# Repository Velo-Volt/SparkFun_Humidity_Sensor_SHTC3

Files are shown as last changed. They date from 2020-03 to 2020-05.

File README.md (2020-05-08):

SparkFun Humidity Sensor - SHTC3 (Qwiic)
========================================

SparkFun Humidity Sensor - SHTC3 (Qwiic) (https://www.sparkfun.com/products/16467)

[*SparkFun Humidity Sensor - SHTC3 (Qwiic)*](https://www.sparkfun.com/products/16467)

The SparkFun Humidity Sensor - SHTC3 (Qwiic) is an I<sup>2</sup>C enabled humidity and temperature sensor.

Repository Contents
-------------------

* **/Documentation** - Data sheets, additional product information
* **/Hardware** - Eagle design files (.brd, .sch)
* **/Production** - Production panel files (.brd)

Documentation
--------------
* **[SHTC3 Arduino Library](https://github.com/sparkfun/SparkFun_SHTC3_Arduino_Library)** - Arduino library for the SHTC3.
* **[Hookup Guide](https://learn.sparkfun.com/tutorials/sparkfun-humidity-sensor-breakout---shtc3-qwiic-hookup-guide)** - Basic hookup guide for the Humidity Sensor - SHTC3 (Qwiic).
* **[SparkFun Fritzing repo](https://github.com/sparkfun/Fritzing_Parts)** - Fritzing diagrams for SparkFun products.
* **[SparkFun 3D Model repo](https://github.com/sparkfun/3D_Models)** - 3D models of SparkFun products. 

Product Versions
----------------
* [SEN-16467](https://www.sparkfun.com/products/16467) - SparkFun Red Version
* [SPX-15074](https://www.sparkfun.com/products/15074) - Original SparkX version of the Humidity Sensor - SHTC3 (Qwiic).

License Information
-------------------

This product is _**open source**_! 

Please review the LICENSE.md file for license information. 

If you have any questions or concerns on licensing, please contact techsupport@sparkfun.com.

Distributed as-is; no warranty is given.

- Your friends at SparkFun.

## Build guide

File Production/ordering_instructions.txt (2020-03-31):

panel size, 143x188mm
PCB thickness, 1.6mm
number of layers, 2
soldermask color, Red
silkscreen color, White
oz copper, 1oz
finish, HASL lead free
stencils, top
pcs per panel, 35
min trace width, 0.1778mm / 0.0070in
min drill size, 0.3810mm / 0.0150in

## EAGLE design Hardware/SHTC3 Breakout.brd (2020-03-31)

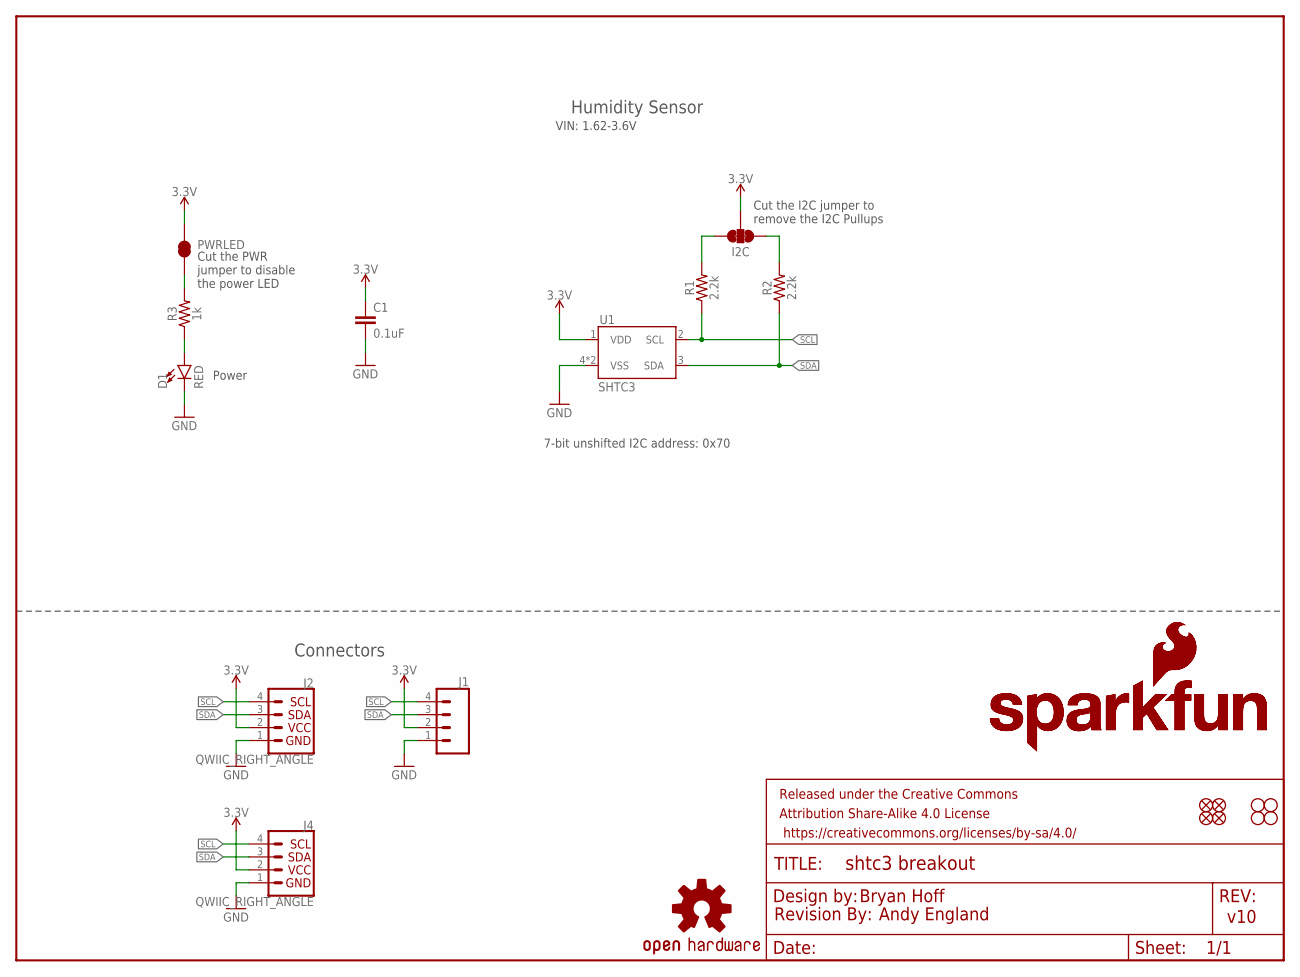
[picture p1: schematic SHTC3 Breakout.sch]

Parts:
C1: 0.1uF; 0603
D1: RED; LED-0603
FRAME1: FRAME-LETTER; CREATIVE_COMMONS
I2C: JUMPER-SMT_3_2-NC_TRACE_SILK; SMT-JUMPER_3_2-NC_TRACE_SILK
J1: CONN_041X04_NO_SILK; 1X04_NO_SILK
J2, J4: QWIIC_RIGHT_ANGLE; JST04_1MM_RA
JP1, JP2, JP5, JP6: FIDUCIALUFIDUCIAL; MICRO-FIDUCIAL
JP3, JP4, JP7, JP8: STAND-OFF
LOGO1: OSHW-LOGOMINI; OSHW-LOGO-MINI
LOGO2, LOGO3: SFE_LOGO_NAME_FLAME.1_INCH; SFE_LOGO_NAME_FLAME_.1
LOGO4: REVISION
PWRLED: JUMPER-SMT_2_NC_TRACE_SILK; SMT-JUMPER_2_NC_TRACE_SILK
R1, R2: 2.2k; 0603
R3: 1k; 0603
U1: SHTC3

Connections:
3.3V: C1.1, I2C.2, J1.2, J2.2, J4.2, PWRLED.2, U1.1 (VDD)
GND: C1.2, D1.C, J1.1, J2.1, J4.1, U1.4 (VSS), U1.5 (VSS)
unnamed: I2C.3, R1.2
unnamed: I2C.1, R2.2
unnamed: D1.A, R3.1
unnamed: PWRLED.1, R3.2
SCL: J1.4, J2.4, J4.4, R1.1, U1.2 (SCL)
SDA: J1.3, J2.3, J4.3, R2.1, U1.3 (SDA)

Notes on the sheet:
Bryan Hoff
v10
7-bit unshifted I2C address: 0x70
Power
Connectors
Cut the I2C jumper to remove the I2C Pullups
Humidity Sensor
Cut the PWR jumper to disable the power LED
Andy England
VIN: 1.62-3.6V

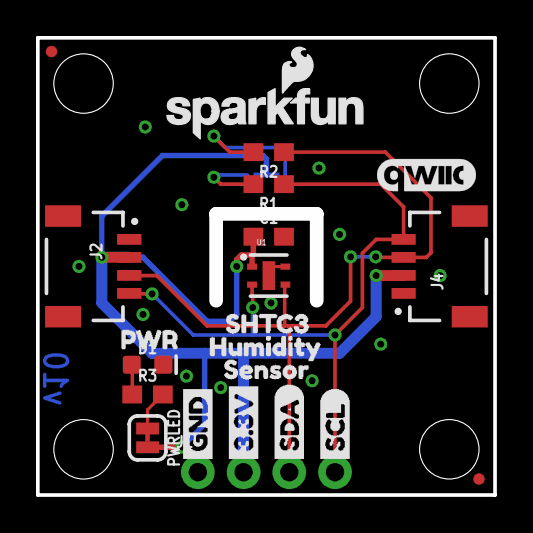
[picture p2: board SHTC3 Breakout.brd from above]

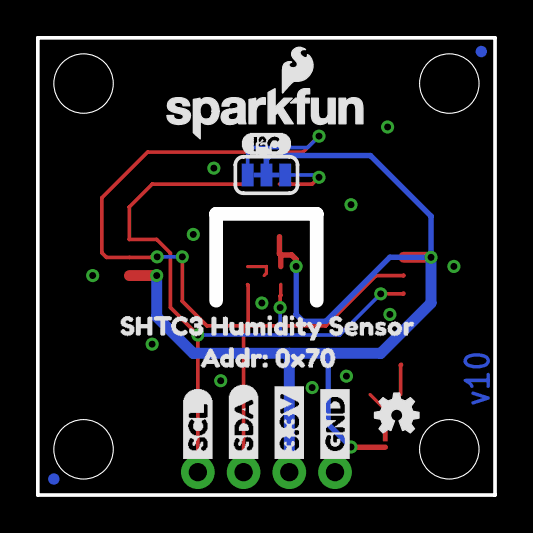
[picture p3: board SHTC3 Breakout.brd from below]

Board: 2 copper layers, 25.4 x 25.4 mm, 40 parts (12 on the bottom side), 8 nets.

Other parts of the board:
U$1: ADDR#_0X700
U$2: PWR_TO
U$3, U$22: GND1
U$4, U$21: 3#3V2
U$5, U$27: SDA8
U$6, U$26: SCL9
U$7: SHTC3_HUMIDITY_SENSOR2
U$8: _SHTC31
U$9: I_SUPER2_C-()-03
U$10: HUMIDITY2
U$11: QWIIC_5.5MM
U$12: SENSOR0

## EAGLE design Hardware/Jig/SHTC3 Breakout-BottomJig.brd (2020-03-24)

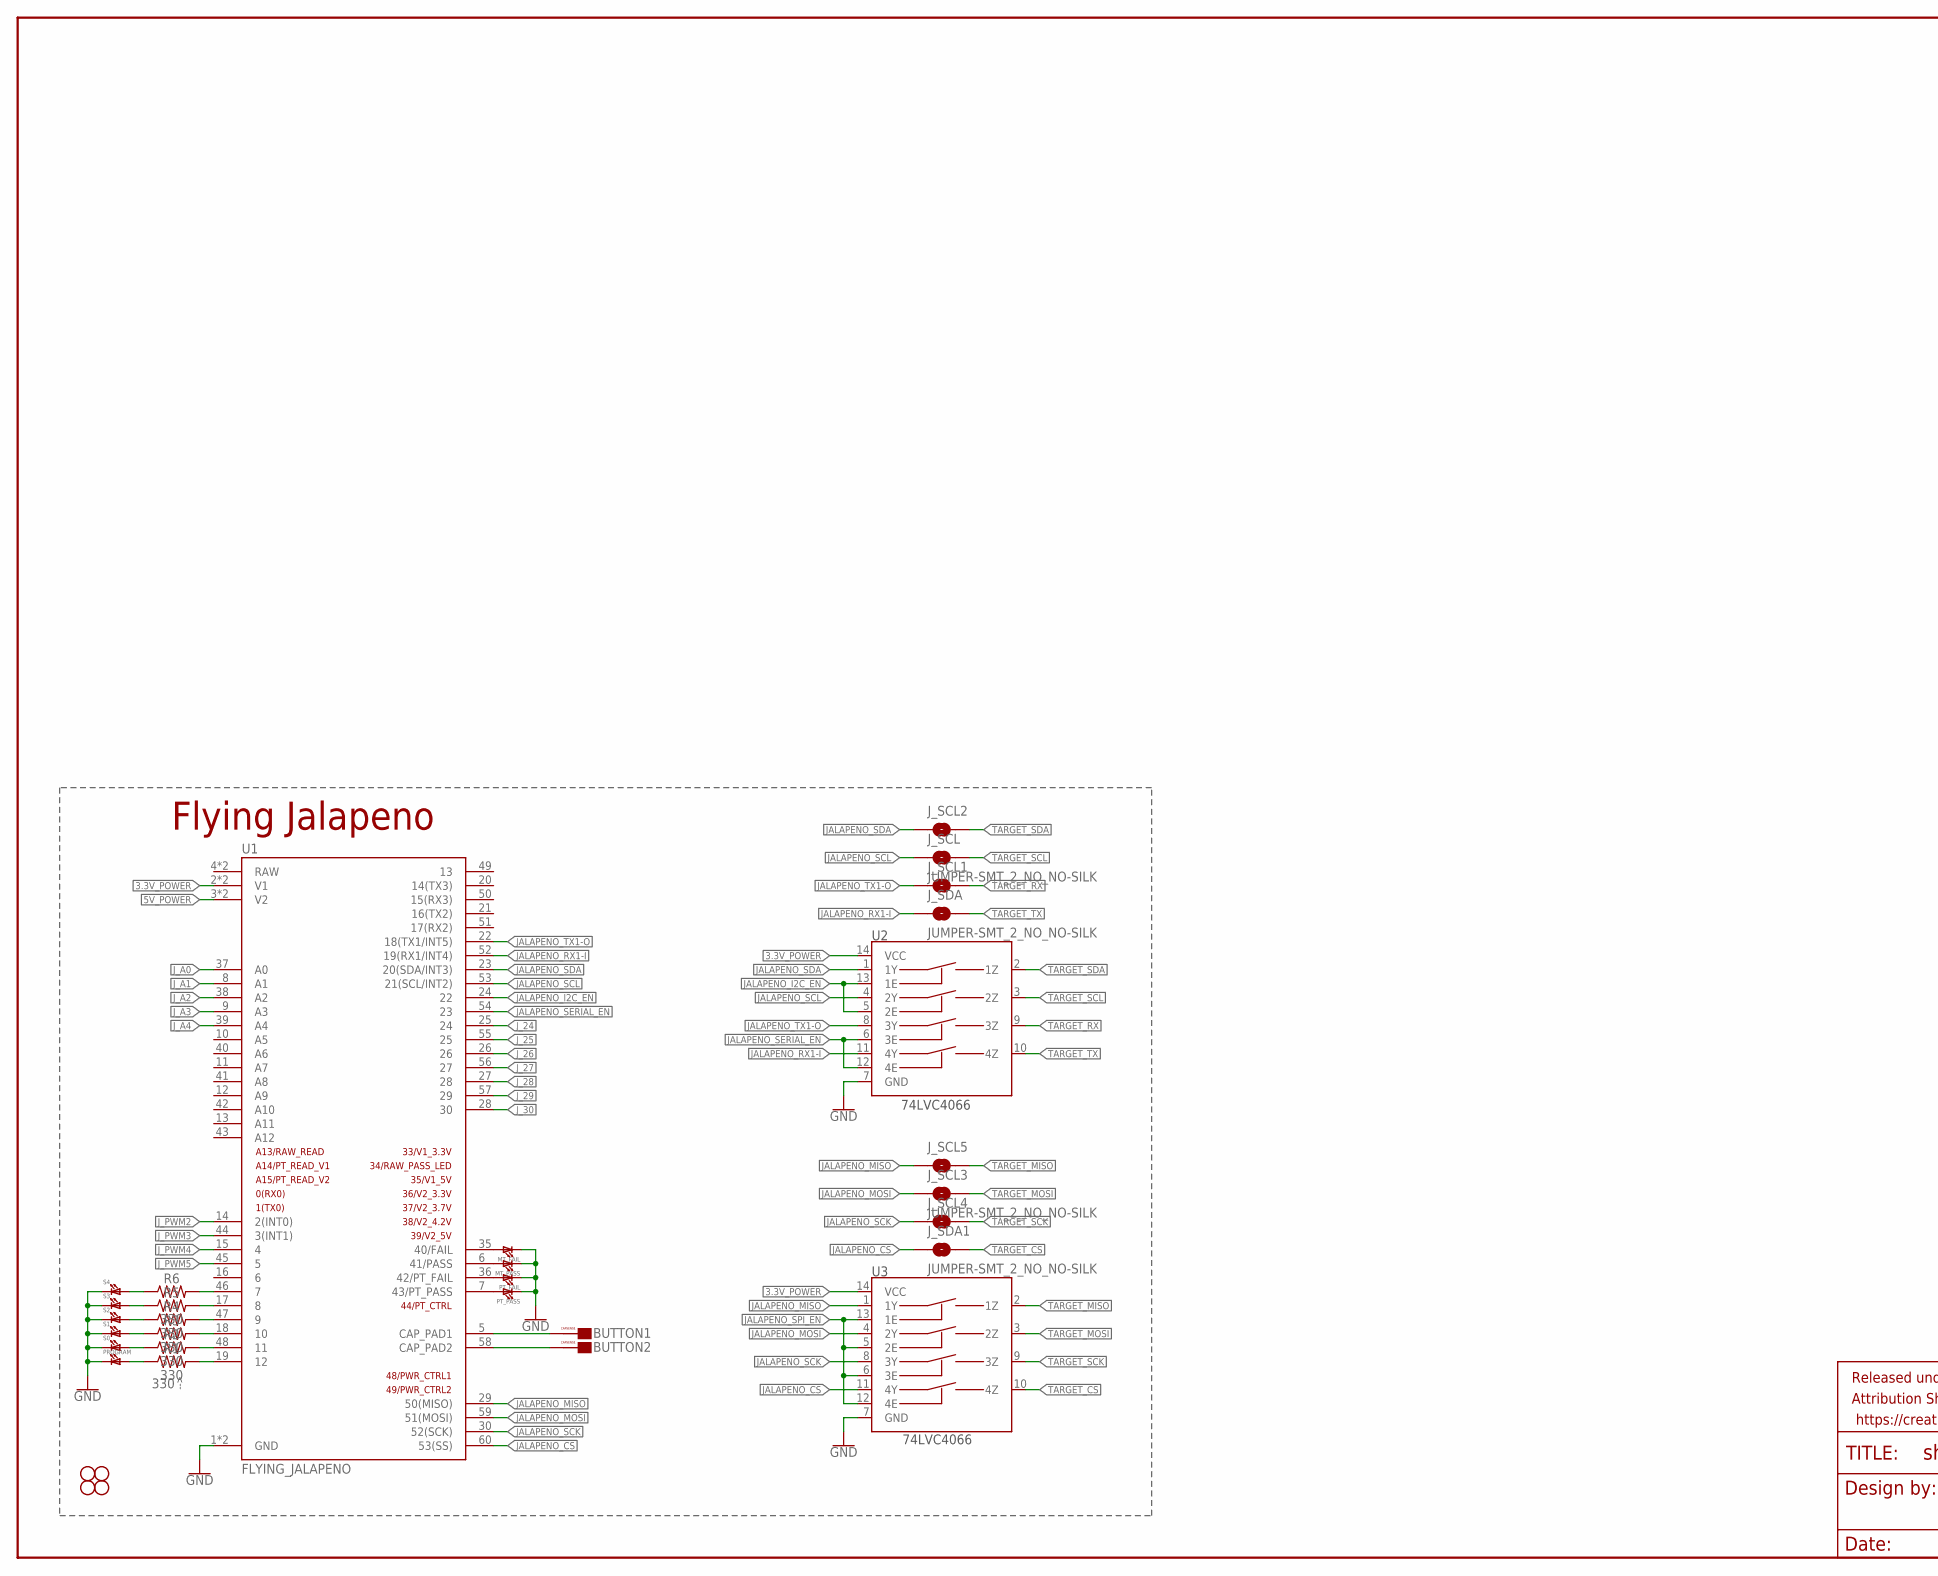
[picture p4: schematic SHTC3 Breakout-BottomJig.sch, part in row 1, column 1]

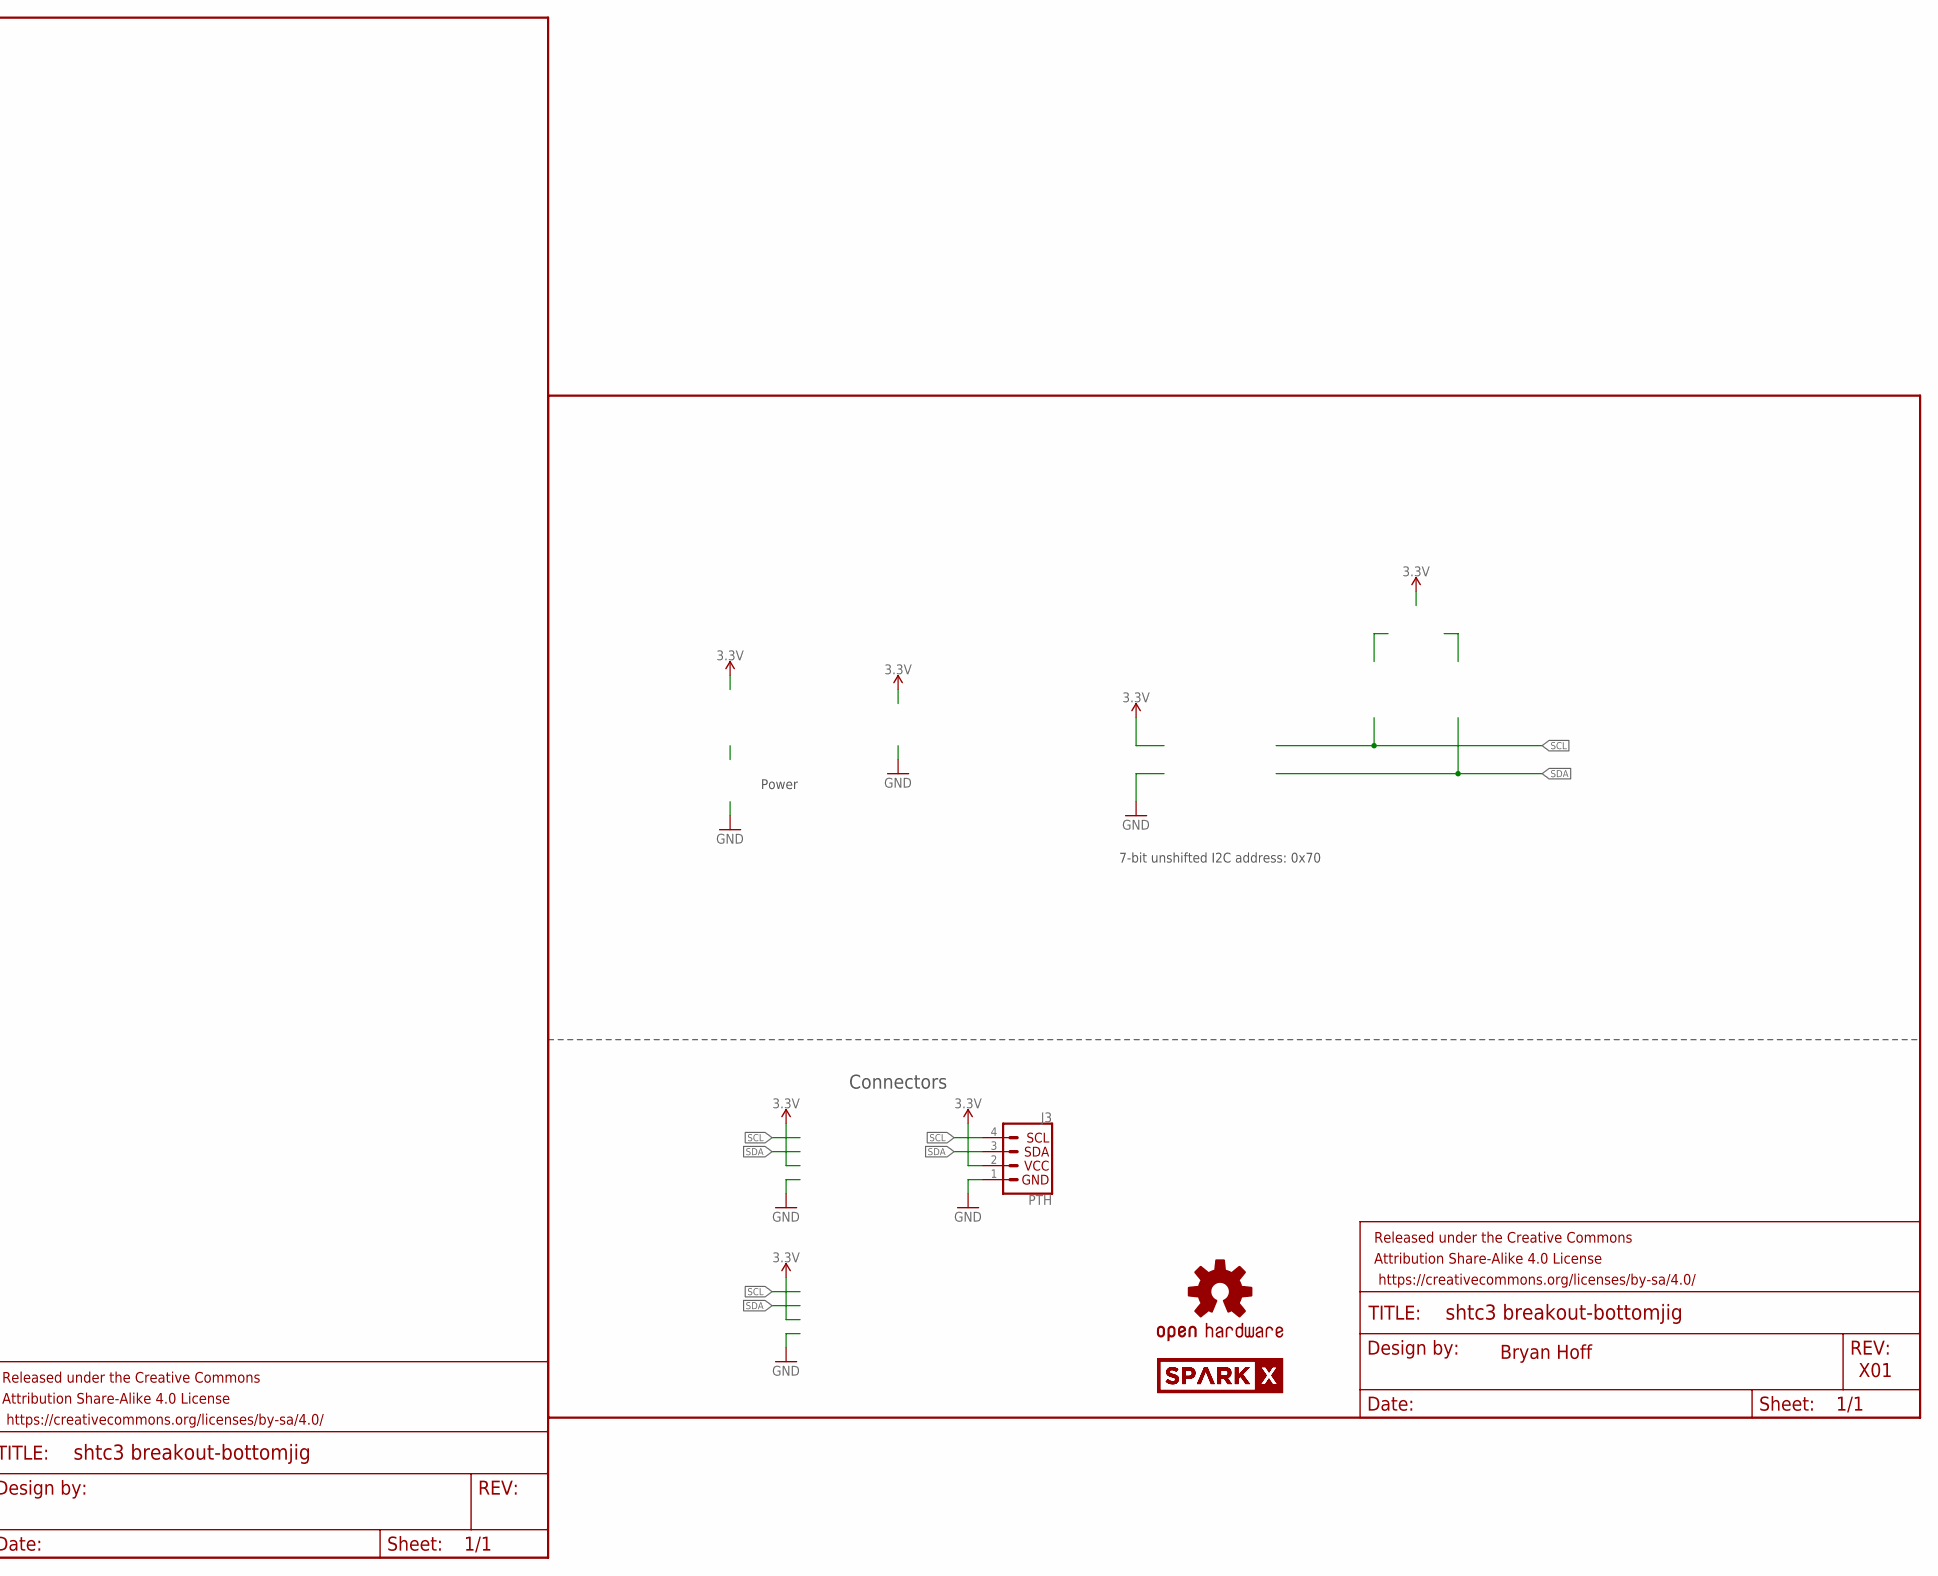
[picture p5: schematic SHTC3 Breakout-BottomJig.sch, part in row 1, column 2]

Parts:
BUTTON1, BUTTON2: CAPSENSE_BUTTON_PAD_ONLY; CAPSENSE_BUTTON_PADS_ONLY
FRAME1: FRAME-LETTER; CREATIVE_COMMONS
FRAME2: FRAME-LEDGER; CREATIVE_COMMONS
H1, H2, H3, H4: STAND-OFF
J3: PTH; 1X04_NO_SILK
J_SCL, J_SCL1, J_SCL2, J_SCL3, J_SCL4, J_SCL5: JUMPER-SMT_2_NO_NO-SILK; SMT-JUMPER_2_NO_NO-SILK
J_SDA, J_SDA1: JUMPER-SMT_2_NO_NO-SILK; SMT-JUMPER_2_NO_NO-SILK
LOGO1: OSHW-LOGOMINI; OSHW-LOGO-MINI
MT_FAIL: LED1206; LED-1206
MT_PASS: LED1206; LED-1206
PROGRAM: LED1206; LED-1206
PT_FAIL: LED1206; LED-1206
PT_PASS: LED1206; LED-1206
R1, R2, R3, R4, R5, R6: 330; 0603
S0, S1, S2, S3, S4: LED1206; LED-1206
U1: FLYING_JALAPENO; FLYING_JALAPENO_V3_M
U2, U3: 74LVC4066; SO14
U$1, U$2: SPARKX-LOGO4; SPARKX-MEDIUM

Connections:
3.3V: J3.2 (VCC)
3.3V_POWER: U1.2 (V1), U1.32 (V1), U2.14 (VCC), U3.14 (VCC)
5V_POWER: U1.3 (V2), U1.33 (V2)
GND: J3.1 (GND), MT_FAIL.C, MT_PASS.C, PROGRAM.C, PT_FAIL.C, PT_PASS.C, S0.C, S1.C, S2.C, S3.C, S4.C, U1.1 (GND), U1.31 (GND), U2.7 (GND), U3.7 (GND)
JALAPENO_CS: J_SDA1.1, U1.60 (53(SS)), U3.11 (4Y)
JALAPENO_I2C_EN: U1.24 (22), U2.5 (2E), U2.13 (1E)
JALAPENO_MISO: J_SCL5.1, U1.29 (50(MISO)), U3.1 (1Y)
JALAPENO_MOSI: J_SCL3.1, U1.59 (51(MOSI)), U3.4 (2Y)
JALAPENO_RX1-I: J_SDA.1, U1.52 (19(RX1/INT4)), U2.11 (4Y)
JALAPENO_SCK: J_SCL4.1, U1.30 (52(SCK)), U3.8 (3Y)
JALAPENO_SCL: J_SCL.1, U1.53 (21(SCL/INT2)), U2.4 (2Y)
JALAPENO_SDA: J_SCL2.1, U1.23 (20(SDA/INT3)), U2.1 (1Y)
JALAPENO_SERIAL_EN: U1.54 (23), U2.6 (3E), U2.12 (4E)
JALAPENO_SPI_EN: U3.5 (2E), U3.6 (3E), U3.12 (4E), U3.13 (1E)
JALAPENO_TX1-O: J_SCL1.1, U1.22 (18(TX1/INT5)), U2.8 (3Y)
J_24: U1.25 (24)
J_25: U1.55 (25)
J_26: U1.26
J_27: U1.56 (27)
J_28: U1.27 (28)
J_29: U1.57 (29)
J_30: U1.28 (30)
J_A0: U1.37 (A0)
J_A1: U1.8 (A1)
J_A2: U1.38 (A2)
J_A3: U1.9 (A3)
J_A4: U1.39 (A4)
J_PWM2: U1.14 (2(INT0))
J_PWM3: U1.44 (3(INT1))
J_PWM4: U1.15 (4)
J_PWM5: U1.45 (5)
unnamed: PT_PASS.A, U1.7 (43/PT_PASS)
unnamed: PT_FAIL.A, U1.36 (42/PT_FAIL)
unnamed: MT_PASS.A, U1.6 (41/PASS)
unnamed: MT_FAIL.A, U1.35 (40/FAIL)
unnamed: BUTTON2.CAPSENSE_PAD, U1.58 (CAP_PAD2)
unnamed: BUTTON1.CAPSENSE_PAD, U1.5 (CAP_PAD1)
unnamed: R6.2, U1.46 (7)
unnamed: R1.2, U1.19 (12)
unnamed: PROGRAM.A, R1.1
unnamed: R5.2, U1.17 (8)
unnamed: R4.2, U1.47 (9)
unnamed: R3.2, U1.18 (10)
unnamed: R2.2, U1.48 (11)
unnamed: R6.1, S4.A
unnamed: R5.1, S3.A
unnamed: R4.1, S2.A
unnamed: R3.1, S1.A
unnamed: R2.1, S0.A
SCL: J3.4 (SCL)
SDA: J3.3 (SDA)
TARGET_CS: J_SDA1.2, U3.10 (4Z)
TARGET_MISO: J_SCL5.2, U3.2 (1Z)
TARGET_MOSI: J_SCL3.2, U3.3 (2Z)
TARGET_RX: J_SCL1.2, U2.9 (3Z)
TARGET_SCK: J_SCL4.2, U3.9 (3Z)
TARGET_SCL: J_SCL.2, U2.3 (2Z)
TARGET_SDA: J_SCL2.2, U2.2 (1Z)
TARGET_TX: J_SDA.2, U2.10 (4Z)

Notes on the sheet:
Bryan Hoff
X01
7-bit unshifted I2C address: 0x70
Power
Connectors
Flying Jalapeno
-->

Board: 2 copper layers, 58 parts (9 on the bottom side), 40 nets, no tracks yet.

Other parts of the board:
U$3, U$22: GND1
U$4, U$21: 3#3V2
U$5, U$27: SDA8
U$6, U$26: SCL9
U$7, U$8: SHTC3_HUMIDITY1
U$9: I_SUPER2_C-()-03
U$10: (PWR)
U$11, U$12, U$13, U$14, U$15, U$16: STAND-OFF-TIGHT
U$29: QWIIC-LOGO-MEDIUM

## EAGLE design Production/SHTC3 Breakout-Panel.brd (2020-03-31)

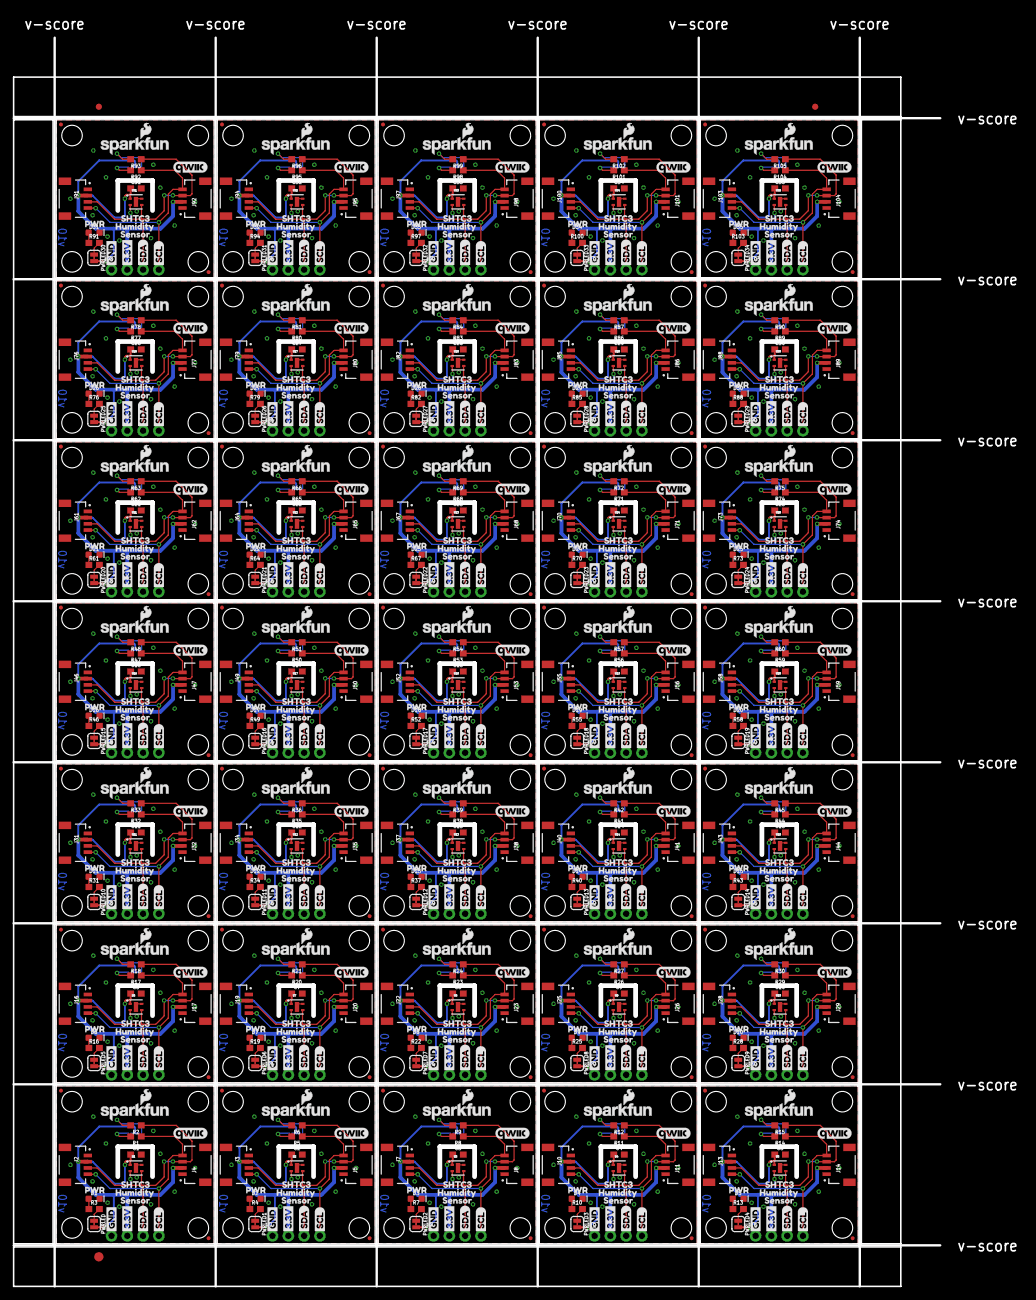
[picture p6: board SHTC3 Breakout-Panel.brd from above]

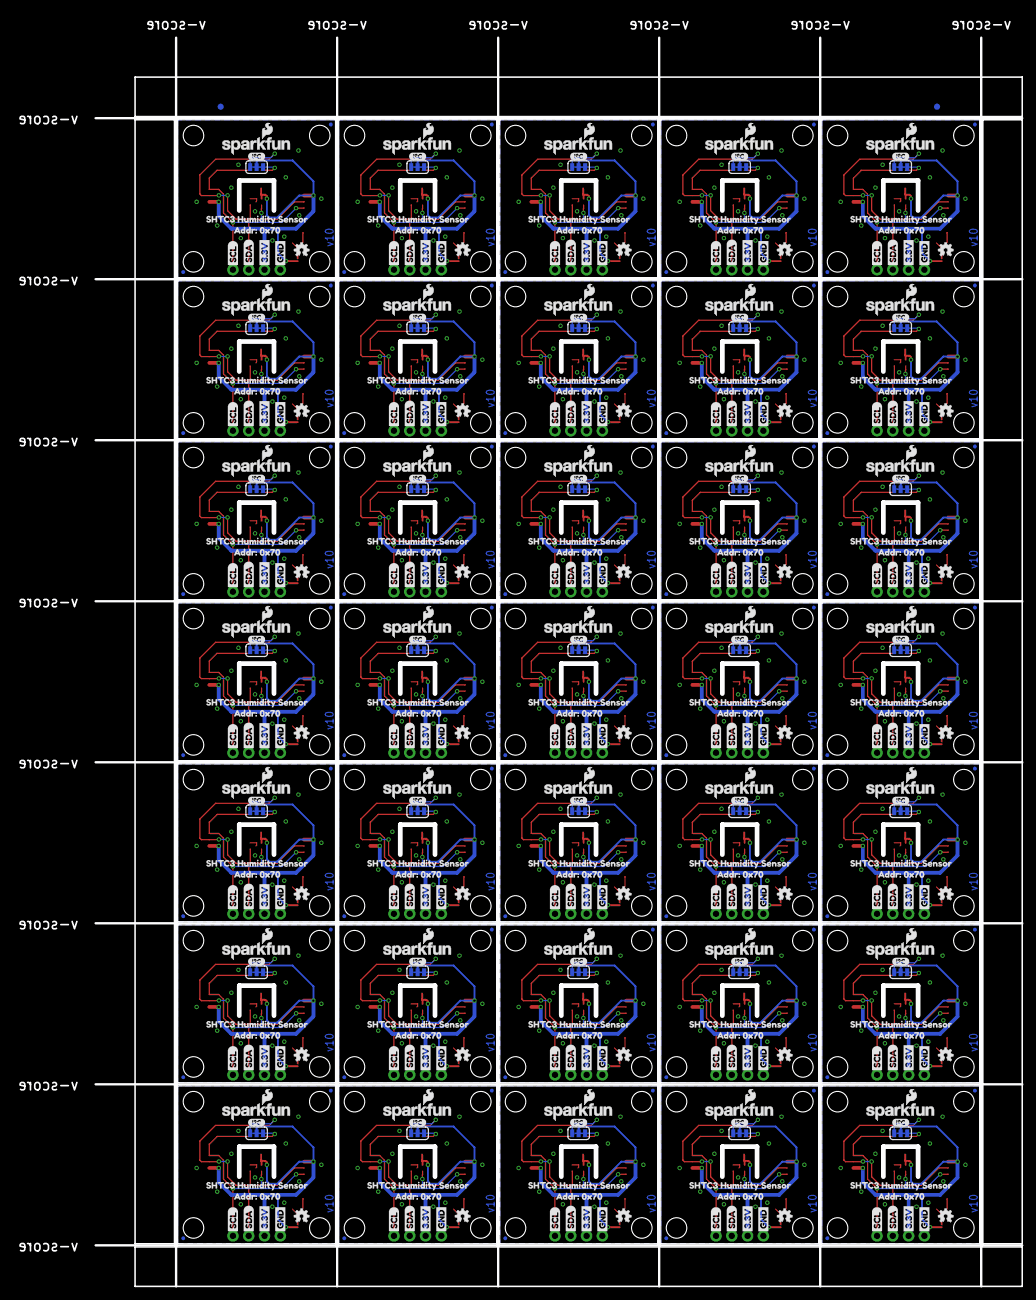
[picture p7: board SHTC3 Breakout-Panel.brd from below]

Board: 2 copper layers, 149.1 x 200.9 mm, 1370 parts (422 on the bottom side), 280 nets.

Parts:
C1, C2, C3, C4, C5, C6, C7, C8, C9, C10, C11, C12, C13, C14, C15, C16, C17, C18, C19, C20, C21, C22, C23, C24, C25, C26, C27, C28, C29, C30, C31, C32, C33, C34, C35: 0.1uF; 0603
D1, D2, D3, D4, D5, D6, D7, D8, D9, D10, D11, D12, D13, D14, D15, D16, D17, D18, D19, D20, D21, D22, D23, D24, D25, D26, D27, D28, D29, D30, D31, D32, D33, D34, D35: RED; LED-0603
E$1, E$2, E$3, E$4: FIDUCIAL-1X2
E$5: FIDUCIAL-1.5X3
I2C, I2C1, I2C2, I2C3, I2C4, I2C5, I2C6, I2C7, I2C8, I2C9, I2C10, I2C11, I2C12, I2C13, I2C14, I2C15, I2C16, I2C17, I2C18, I2C19, I2C20, I2C21, I2C22, I2C23, I2C24, I2C25, I2C26, I2C27, I2C28, I2C29, I2C30, I2C31, I2C32, I2C33, I2C34: JUMPER-SMT_3_2-NC_TRACE_SILK; SMT-JUMPER_3_2-NC_TRACE_SILK
J1, J6, J9, J12, J15, J18, J21, J24, J27, J30, J33, J36, J39, J42, J45, J48, J51, J54, J57, J60, J63, J66, J69, J72, J75, J78, J81, J84, J87, J90, J93, J96, J99, J102, J105: 1X04_NO_SILK
J2, J3, J4, J5, J7, J8, J10, J11, J13, J14, J16, J17, J19, J20, J22, J23, J25, J26, J28, J29, J31, J32, J34, J35, J37, J38, J40, J41, J43, J44, J46, J47, J49, J50, J52, J53, J55, J56, J58, J59, J61, J62, J64, J65, J67, J68, J70, J71, J73, J74, J76, J77, J79, J80, J82, J83, J85, J86, J88, J89, J91, J92, J94, J95, J97, J98, J100, J101, J103, J104: QWIIC_RIGHT_ANGLE; JST04_1MM_RA
JP1, JP2, JP5, JP6, JP11, JP12, JP13, JP14, JP19, JP20, JP21, JP22, JP27, JP28, JP29, JP30, JP35, JP36, JP37, JP38, JP43, JP44, JP45, JP46, JP51, JP52, JP53, JP54, JP59, JP60, JP61, JP62, JP67, JP68, JP69, JP70, JP75, JP76, JP77, JP78, JP83, JP84, JP85, JP86, JP91, JP92, JP93, JP94, JP99, JP100, JP101, JP102, JP107, JP108, JP109, JP110, JP115, JP116, JP117, JP118, JP123, JP124, JP125, JP126, JP131, JP132, JP133, JP134, JP139, JP140, JP141, JP142, JP147, JP148, JP149, JP150, JP155, JP156, JP157, JP158, JP163, JP164, JP165, JP166, JP171, JP172, JP173, JP174, JP179, JP180, JP181, JP182, JP187, JP188, JP189, JP190, JP195, JP196, JP197, JP198, JP203, JP204, JP205, JP206, JP211, JP212, JP213, JP214, JP219, JP220, JP221, JP222, JP227, JP228, JP229, JP230, JP235, JP236, JP237, JP238, JP243, JP244, JP245, JP246, JP251, JP252, JP253, JP254, JP259, JP260, JP261, JP262, JP267, JP268, JP269, JP270, JP275, JP276, JP277, JP278: FIDUCIALUFIDUCIAL; MICRO-FIDUCIAL
JP3, JP4, JP7, JP8, JP9, JP10, JP15, JP16, JP17, JP18, JP23, JP24, JP25, JP26, JP31, JP32, JP33, JP34, JP39, JP40, JP41, JP42, JP47, JP48, JP49, JP50, JP55, JP56, JP57, JP58, JP63, JP64, JP65, JP66, JP71, JP72, JP73, JP74, JP79, JP80, JP81, JP82, JP87, JP88, JP89, JP90, JP95, JP96, JP97, JP98, JP103, JP104, JP105, JP106, JP111, JP112, JP113, JP114, JP119, JP120, JP121, JP122, JP127, JP128, JP129, JP130, JP135, JP136, JP137, JP138, JP143, JP144, JP145, JP146, JP151, JP152, JP153, JP154, JP159, JP160, JP161, JP162, JP167, JP168, JP169, JP170, JP175, JP176, JP177, JP178, JP183, JP184, JP185, JP186, JP191, JP192, JP193, JP194, JP199, JP200, JP201, JP202, JP207, JP208, JP209, JP210, JP215, JP216, JP217, JP218, JP223, JP224, JP225, JP226, JP231, JP232, JP233, JP234, JP239, JP240, JP241, JP242, JP247, JP248, JP249, JP250, JP255, JP256, JP257, JP258, JP263, JP264, JP265, JP266, JP271, JP272, JP273, JP274, JP279, JP280: STAND-OFF
LOGO1, LOGO5, LOGO9, LOGO13, LOGO17, LOGO21, LOGO25, LOGO29, LOGO33, LOGO37, LOGO41, LOGO45, LOGO49, LOGO53, LOGO57, LOGO61, LOGO65, LOGO69, LOGO73, LOGO77, LOGO81, LOGO85, LOGO89, LOGO93, LOGO97, LOGO101, LOGO105, LOGO109, LOGO113, LOGO117, LOGO121, LOGO125, LOGO129, LOGO133, LOGO137: OSHW-LOGOMINI; OSHW-LOGO-MINI
LOGO2, LOGO3, LOGO6, LOGO7, LOGO10, LOGO11, LOGO14, LOGO15, LOGO18, LOGO19, LOGO22, LOGO23, LOGO26, LOGO27, LOGO30, LOGO31, LOGO34, LOGO35, LOGO38, LOGO39, LOGO42, LOGO43, LOGO46, LOGO47, LOGO50, LOGO51, LOGO54, LOGO55, LOGO58, LOGO59, LOGO62, LOGO63, LOGO66, LOGO67, LOGO70, LOGO71, LOGO74, LOGO75, LOGO78, LOGO79, LOGO82, LOGO83, LOGO86, LOGO87, LOGO90, LOGO91, LOGO94, LOGO95, LOGO98, LOGO99, LOGO102, LOGO103, LOGO106, LOGO107, LOGO110, LOGO111, LOGO114, LOGO115, LOGO118, LOGO119, LOGO122, LOGO123, LOGO126, LOGO127, LOGO130, LOGO131, LOGO134, LOGO135, LOGO138, LOGO139: SFE_LOGO_NAME_FLAME.1_INCH; SFE_LOGO_NAME_FLAME_.1
LOGO4, LOGO8, LOGO12, LOGO16, LOGO20, LOGO24, LOGO28, LOGO32, LOGO36, LOGO40, LOGO44, LOGO48, LOGO52, LOGO56, LOGO60, LOGO64, LOGO68, LOGO72, LOGO76, LOGO80, LOGO84, LOGO88, LOGO92, LOGO96, LOGO100, LOGO104, LOGO108, LOGO112, LOGO116, LOGO120, LOGO124, LOGO128, LOGO132, LOGO136, LOGO140: REVISION
PWRLED, PWRLED1, PWRLED2, PWRLED3, PWRLED4, PWRLED5, PWRLED6, PWRLED7, PWRLED8, PWRLED9, PWRLED10, PWRLED11, PWRLED12, PWRLED13, PWRLED14, PWRLED15, PWRLED16, PWRLED17, PWRLED18, PWRLED19, PWRLED20, PWRLED21, PWRLED22, PWRLED23, PWRLED24, PWRLED25, PWRLED26, PWRLED27, PWRLED28, PWRLED29, PWRLED30, PWRLED31, PWRLED32, PWRLED33, PWRLED34: JUMPER-SMT_2_NC_TRACE_SILK; SMT-JUMPER_2_NC_TRACE_SILK
R1, R2, R5, R6, R8, R9, R11, R12, R14, R15, R17, R18, R20, R21, R23, R24, R26, R27, R29, R30, R32, R33, R35, R36, R38, R39, R41, R42, R44, R45, R47, R48, R50, R51, R53, R54, R56, R57, R59, R60, R62, R63, R65, R66, R68, R69, R71, R72, R74, R75, R77, R78, R80, R81, R83, R84, R86, R87, R89, R90, R92, R93, R95, R96, R98, R99, R101, R102, R104, R105: 2.2k; 0603
R3, R4, R7, R10, R13, R16, R19, R22, R25, R28, R31, R34, R37, R40, R43, R46, R49, R52, R55, R58, R61, R64, R67, R70, R73, R76, R79, R82, R85, R88, R91, R94, R97, R100, R103: 1k; 0603
U1, U2, U3, U4, U5, U6, U7, U8, U9, U10, U11, U12, U13, U14, U15, U16, U17, U18, U19, U20, U21, U22, U23, U24, U25, U26, U27, U28, U29, U30, U31, U32, U33, U34, U35: SHTC3
U$1, U$25, U$43, U$59, U$75, U$91, U$107, U$123, U$139, U$155, U$171, U$187, U$203, U$219, U$235, U$251, U$267, U$283, U$299, U$315, U$331, U$347, U$363, U$379, U$395, U$411, U$427, U$443, U$459, U$475, U$491, U$507, U$523, U$539, U$555: ADDR#_0X700
U$2, U$28, U$44, U$60, U$76, U$92, U$108, U$124, U$140, U$156, U$172, U$188, U$204, U$220, U$236, U$252, U$268, U$284, U$300, U$316, U$332, U$348, U$364, U$380, U$396, U$412, U$428, U$444, U$460, U$476, U$492, U$508, U$524, U$540, U$556: PWR_TO
U$3, U$14, U$17, U$22, U$34, U$37, U$50, U$53, U$66, U$69, U$82, U$85, U$98, U$101, U$114, U$117, U$130, U$133, U$146, U$149, U$162, U$165, U$178, U$181, U$194, U$197, U$210, U$213, U$226, U$229, U$242, U$245, U$258, U$261, U$274, U$277, U$290, U$293, U$306, U$309, U$322, U$325, U$338, U$341, U$354, U$357, U$370, U$373, U$386, U$389, U$402, U$405, U$418, U$421, U$434, U$437, U$450, U$453, U$466, U$469, U$482, U$485, U$498, U$501, U$514, U$517, U$530, U$533, U$546, U$549: GND1
U$4, U$13, U$18, U$21, U$33, U$38, U$49, U$54, U$65, U$70, U$81, U$86, U$97, U$102, U$113, U$118, U$129, U$134, U$145, U$150, U$161, U$166, U$177, U$182, U$193, U$198, U$209, U$214, U$225, U$230, U$241, U$246, U$257, U$262, U$273, U$278, U$289, U$294, U$305, U$310, U$321, U$326, U$337, U$342, U$353, U$358, U$369, U$374, U$385, U$390, U$401, U$406, U$417, U$422, U$433, U$438, U$449, U$454, U$465, U$470, U$481, U$486, U$497, U$502, U$513, U$518, U$529, U$534, U$545, U$550: 3#3V2
U$5, U$16, U$19, U$27, U$36, U$39, U$52, U$55, U$68, U$71, U$84, U$87, U$100, U$103, U$116, U$119, U$132, U$135, U$148, U$151, U$164, U$167, U$180, U$183, U$196, U$199, U$212, U$215, U$228, U$231, U$244, U$247, U$260, U$263, U$276, U$279, U$292, U$295, U$308, U$311, U$324, U$327, U$340, U$343, U$356, U$359, U$372, U$375, U$388, U$391, U$404, U$407, U$420, U$423, U$436, U$439, U$452, U$455, U$468, U$471, U$484, U$487, U$500, U$503, U$516, U$519, U$532, U$535, U$548, U$551: SDA8
U$6, U$15, U$20, U$26, U$35, U$40, U$51, U$56, U$67, U$72, U$83, U$88, U$99, U$104, U$115, U$120, U$131, U$136, U$147, U$152, U$163, U$168, U$179, U$184, U$195, U$200, U$211, U$216, U$227, U$232, U$243, U$248, U$259, U$264, U$275, U$280, U$291, U$296, U$307, U$312, U$323, U$328, U$339, U$344, U$355, U$360, U$371, U$376, U$387, U$392, U$403, U$408, U$419, U$424, U$435, U$440, U$451, U$456, U$467, U$472, U$483, U$488, U$499, U$504, U$515, U$520, U$531, U$536, U$547, U$552: SCL9
U$7, U$32, U$48, U$64, U$80, U$96, U$112, U$128, U$144, U$160, U$176, U$192, U$208, U$224, U$240, U$256, U$272, U$288, U$304, U$320, U$336, U$352, U$368, U$384, U$400, U$416, U$432, U$448, U$464, U$480, U$496, U$512, U$528, U$544, U$560: SHTC3_HUMIDITY_SENSOR2
U$8, U$29, U$45, U$61, U$77, U$93, U$109, U$125, U$141, U$157, U$173, U$189, U$205, U$221, U$237, U$253, U$269, U$285, U$301, U$317, U$333, U$349, U$365, U$381, U$397, U$413, U$429, U$445, U$461, U$477, U$493, U$509, U$525, U$541, U$557: _SHTC31
U$9, U$23, U$41, U$57, U$73, U$89, U$105, U$121, U$137, U$153, U$169, U$185, U$201, U$217, U$233, U$249, U$265, U$281, U$297, U$313, U$329, U$345, U$361, U$377, U$393, U$409, U$425, U$441, U$457, U$473, U$489, U$505, U$521, U$537, U$553: I_SUPER2_C-()-03
U$10, U$30, U$46, U$62, U$78, U$94, U$110, U$126, U$142, U$158, U$174, U$190, U$206, U$222, U$238, U$254, U$270, U$286, U$302, U$318, U$334, U$350, U$366, U$382, U$398, U$414, U$430, U$446, U$462, U$478, U$494, U$510, U$526, U$542, U$558: HUMIDITY2
U$11, U$24, U$42, U$58, U$74, U$90, U$106, U$122, U$138, U$154, U$170, U$186, U$202, U$218, U$234, U$250, U$266, U$282, U$298, U$314, U$330, U$346, U$362, U$378, U$394, U$410, U$426, U$442, U$458, U$474, U$490, U$506, U$522, U$538, U$554: QWIIC_5.5MM
U$12, U$31, U$47, U$63, U$79, U$95, U$111, U$127, U$143, U$159, U$175, U$191, U$207, U$223, U$239, U$255, U$271, U$287, U$303, U$319, U$335, U$351, U$367, U$383, U$399, U$415, U$431, U$447, U$463, U$479, U$495, U$511, U$527, U$543, U$559: SENSOR0

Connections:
3.3V: C1.1, I2C.2, J1.2, J2.2, J4.2, PWRLED.2, U1.1
3.3V1: C2.1, I2C1.2, J3.2, J5.2, J6.2, PWRLED1.2, U2.1
3.3V2: C3.1, I2C2.2, J7.2, J8.2, J9.2, PWRLED2.2, U3.1
3.3V3: C4.1, I2C3.2, J10.2, J11.2, J12.2, PWRLED3.2, U4.1
3.3V4: C5.1, I2C4.2, J13.2, J14.2, J15.2, PWRLED4.2, U5.1
3.3V5: C6.1, I2C5.2, J16.2, J17.2, J18.2, PWRLED5.2, U6.1
3.3V6: C7.1, I2C6.2, J19.2, J20.2, J21.2, PWRLED6.2, U7.1
3.3V7: C8.1, I2C7.2, J22.2, J23.2, J24.2, PWRLED7.2, U8.1
3.3V8: C9.1, I2C8.2, J25.2, J26.2, J27.2, PWRLED8.2, U9.1
3.3V9: C10.1, I2C9.2, J28.2, J29.2, J30.2, PWRLED9.2, U10.1
3.3V10: C11.1, I2C10.2, J31.2, J32.2, J33.2, PWRLED10.2, U11.1
3.3V11: C12.1, I2C11.2, J34.2, J35.2, J36.2, PWRLED11.2, U12.1
3.3V12: C13.1, I2C12.2, J37.2, J38.2, J39.2, PWRLED12.2, U13.1
3.3V13: C14.1, I2C13.2, J40.2, J41.2, J42.2, PWRLED13.2, U14.1
3.3V14: C15.1, I2C14.2, J43.2, J44.2, J45.2, PWRLED14.2, U15.1
3.3V15: C16.1, I2C15.2, J46.2, J47.2, J48.2, PWRLED15.2, U16.1
3.3V16: C17.1, I2C16.2, J49.2, J50.2, J51.2, PWRLED16.2, U17.1
3.3V17: C18.1, I2C17.2, J52.2, J53.2, J54.2, PWRLED17.2, U18.1
3.3V18: C19.1, I2C18.2, J55.2, J56.2, J57.2, PWRLED18.2, U19.1
3.3V19: C20.1, I2C19.2, J58.2, J59.2, J60.2, PWRLED19.2, U20.1
3.3V20: C21.1, I2C20.2, J61.2, J62.2, J63.2, PWRLED20.2, U21.1
3.3V21: C22.1, I2C21.2, J64.2, J65.2, J66.2, PWRLED21.2, U22.1
3.3V22: C23.1, I2C22.2, J67.2, J68.2, J69.2, PWRLED22.2, U23.1
3.3V23: C24.1, I2C23.2, J70.2, J71.2, J72.2, PWRLED23.2, U24.1
3.3V24: C25.1, I2C24.2, J73.2, J74.2, J75.2, PWRLED24.2, U25.1
3.3V25: C26.1, I2C25.2, J76.2, J77.2, J78.2, PWRLED25.2, U26.1
3.3V26: C27.1, I2C26.2, J79.2, J80.2, J81.2, PWRLED26.2, U27.1
3.3V27: C28.1, I2C27.2, J82.2, J83.2, J84.2, PWRLED27.2, U28.1
3.3V28: C29.1, I2C28.2, J85.2, J86.2, J87.2, PWRLED28.2, U29.1
3.3V29: C30.1, I2C29.2, J88.2, J89.2, J90.2, PWRLED29.2, U30.1
3.3V30: C31.1, I2C30.2, J91.2, J92.2, J93.2, PWRLED30.2, U31.1
3.3V31: C32.1, I2C31.2, J94.2, J95.2, J96.2, PWRLED31.2, U32.1
3.3V32: C33.1, I2C32.2, J97.2, J98.2, J99.2, PWRLED32.2, U33.1
3.3V33: C34.1, I2C33.2, J100.2, J101.2, J102.2, PWRLED33.2, U34.1
3.3V34: C35.1, I2C34.2, J103.2, J104.2, J105.2, PWRLED34.2, U35.1
GND: C1.2, D1.C, J1.1, J2.1, J4.1, U1.4, U1.5
GND1: C2.2, D2.C, J3.1, J5.1, J6.1, U2.4, U2.5
GND2: C3.2, D3.C, J7.1, J8.1, J9.1, U3.4, U3.5
GND3: C4.2, D4.C, J10.1, J11.1, J12.1, U4.4, U4.5
GND4: C5.2, D5.C, J13.1, J14.1, J15.1, U5.4, U5.5
GND5: C6.2, D6.C, J16.1, J17.1, J18.1, U6.4, U6.5
GND6: C7.2, D7.C, J19.1, J20.1, J21.1, U7.4, U7.5
GND7: C8.2, D8.C, J22.1, J23.1, J24.1, U8.4, U8.5
GND8: C9.2, D9.C, J25.1, J26.1, J27.1, U9.4, U9.5
GND9: C10.2, D10.C, J28.1, J29.1, J30.1, U10.4, U10.5
GND10: C11.2, D11.C, J31.1, J32.1, J33.1, U11.4, U11.5
GND11: C12.2, D12.C, J34.1, J35.1, J36.1, U12.4, U12.5
GND12: C13.2, D13.C, J37.1, J38.1, J39.1, U13.4, U13.5
GND13: C14.2, D14.C, J40.1, J41.1, J42.1, U14.4, U14.5
GND14: C15.2, D15.C, J43.1, J44.1, J45.1, U15.4, U15.5
GND15: C16.2, D16.C, J46.1, J47.1, J48.1, U16.4, U16.5
GND16: C17.2, D17.C, J49.1, J50.1, J51.1, U17.4, U17.5
GND17: C18.2, D18.C, J52.1, J53.1, J54.1, U18.4, U18.5
GND18: C19.2, D19.C, J55.1, J56.1, J57.1, U19.4, U19.5
GND19: C20.2, D20.C, J58.1, J59.1, J60.1, U20.4, U20.5
GND20: C21.2, D21.C, J61.1, J62.1, J63.1, U21.4, U21.5
GND21: C22.2, D22.C, J64.1, J65.1, J66.1, U22.4, U22.5
GND22: C23.2, D23.C, J67.1, J68.1, J69.1, U23.4, U23.5
GND23: C24.2, D24.C, J70.1, J71.1, J72.1, U24.4, U24.5
GND24: C25.2, D25.C, J73.1, J74.1, J75.1, U25.4, U25.5
GND25: C26.2, D26.C, J76.1, J77.1, J78.1, U26.4, U26.5
GND26: C27.2, D27.C, J79.1, J80.1, J81.1, U27.4, U27.5
GND27: C28.2, D28.C, J82.1, J83.1, J84.1, U28.4, U28.5
GND28: C29.2, D29.C, J85.1, J86.1, J87.1, U29.4, U29.5
GND29: C30.2, D30.C, J88.1, J89.1, J90.1, U30.4, U30.5
GND30: C31.2, D31.C, J91.1, J92.1, J93.1, U31.4, U31.5
GND31: C32.2, D32.C, J94.1, J95.1, J96.1, U32.4, U32.5
GND32: C33.2, D33.C, J97.1, J98.1, J99.1, U33.4, U33.5
GND33: C34.2, D34.C, J100.1, J101.1, J102.1, U34.4, U34.5
GND34: C35.2, D35.C, J103.1, J104.1, J105.1, U35.4, U35.5
unnamed: I2C.3, R1.2
unnamed: I2C.1, R2.2
unnamed: D1.A, R3.1
unnamed: PWRLED.1, R3.2
unnamed: D2.A, R4.1
unnamed: I2C1.3, R5.2
unnamed: I2C1.1, R6.2
unnamed: PWRLED1.1, R4.2
unnamed: D3.A, R7.1
unnamed: I2C2.3, R8.2
unnamed: I2C2.1, R9.2
unnamed: PWRLED2.1, R7.2
unnamed: D4.A, R10.1
unnamed: I2C3.3, R11.2
unnamed: I2C3.1, R12.2
unnamed: PWRLED3.1, R10.2
unnamed: D5.A, R13.1
unnamed: I2C4.3, R14.2
unnamed: I2C4.1, R15.2
unnamed: PWRLED4.1, R13.2
unnamed: D6.A, R16.1
unnamed: I2C5.3, R17.2
unnamed: I2C5.1, R18.2
unnamed: PWRLED5.1, R16.2
unnamed: D7.A, R19.1
unnamed: I2C6.3, R20.2
unnamed: I2C6.1, R21.2
unnamed: PWRLED6.1, R19.2
unnamed: D8.A, R22.1
unnamed: I2C7.3, R23.2
unnamed: I2C7.1, R24.2
unnamed: PWRLED7.1, R22.2
unnamed: D9.A, R25.1
unnamed: I2C8.3, R26.2
unnamed: I2C8.1, R27.2
unnamed: PWRLED8.1, R25.2
unnamed: D10.A, R28.1
unnamed: I2C9.3, R29.2
unnamed: I2C9.1, R30.2
unnamed: PWRLED9.1, R28.2
unnamed: D11.A, R31.1
unnamed: I2C10.3, R32.2
unnamed: I2C10.1, R33.2
unnamed: PWRLED10.1, R31.2
unnamed: D12.A, R34.1
unnamed: I2C11.3, R35.2
unnamed: I2C11.1, R36.2
unnamed: PWRLED11.1, R34.2
unnamed: D13.A, R37.1
unnamed: I2C12.3, R38.2
unnamed: I2C12.1, R39.2
unnamed: PWRLED12.1, R37.2
unnamed: D14.A, R40.1
unnamed: I2C13.3, R41.2
unnamed: I2C13.1, R42.2
unnamed: PWRLED13.1, R40.2
unnamed: D15.A, R43.1
unnamed: I2C14.3, R44.2
unnamed: I2C14.1, R45.2
unnamed: PWRLED14.1, R43.2
unnamed: D16.A, R46.1
unnamed: I2C15.3, R47.2
unnamed: I2C15.1, R48.2
unnamed: PWRLED15.1, R46.2
unnamed: D17.A, R49.1
unnamed: I2C16.3, R50.2
unnamed: I2C16.1, R51.2
unnamed: PWRLED16.1, R49.2
unnamed: D18.A, R52.1
unnamed: I2C17.3, R53.2
unnamed: I2C17.1, R54.2
unnamed: PWRLED17.1, R52.2
unnamed: D19.A, R55.1
unnamed: I2C18.3, R56.2
unnamed: I2C18.1, R57.2
unnamed: PWRLED18.1, R55.2
unnamed: D20.A, R58.1
unnamed: I2C19.3, R59.2
unnamed: I2C19.1, R60.2
unnamed: PWRLED19.1, R58.2
unnamed: D21.A, R61.1
unnamed: I2C20.3, R62.2
unnamed: I2C20.1, R63.2
unnamed: PWRLED20.1, R61.2
unnamed: D22.A, R64.1
unnamed: I2C21.3, R65.2
unnamed: I2C21.1, R66.2
unnamed: PWRLED21.1, R64.2
unnamed: D23.A, R67.1
unnamed: I2C22.3, R68.2
unnamed: I2C22.1, R69.2
unnamed: PWRLED22.1, R67.2
unnamed: D24.A, R70.1
unnamed: I2C23.3, R71.2
unnamed: I2C23.1, R72.2
unnamed: PWRLED23.1, R70.2
unnamed: D25.A, R73.1
unnamed: I2C24.3, R74.2
unnamed: I2C24.1, R75.2
unnamed: PWRLED24.1, R73.2
unnamed: D26.A, R76.1
unnamed: I2C25.3, R77.2
unnamed: I2C25.1, R78.2
unnamed: PWRLED25.1, R76.2
unnamed: D27.A, R79.1
unnamed: I2C26.3, R80.2
unnamed: I2C26.1, R81.2
unnamed: PWRLED26.1, R79.2
unnamed: D28.A, R82.1
unnamed: I2C27.3, R83.2
unnamed: I2C27.1, R84.2
unnamed: PWRLED27.1, R82.2
unnamed: D29.A, R85.1
unnamed: I2C28.3, R86.2
unnamed: I2C28.1, R87.2
unnamed: PWRLED28.1, R85.2
unnamed: D30.A, R88.1
unnamed: I2C29.3, R89.2
unnamed: I2C29.1, R90.2
unnamed: PWRLED29.1, R88.2
unnamed: D31.A, R91.1
unnamed: I2C30.3, R92.2
unnamed: I2C30.1, R93.2
unnamed: PWRLED30.1, R91.2
unnamed: D32.A, R94.1
unnamed: I2C31.3, R95.2
unnamed: I2C31.1, R96.2
unnamed: PWRLED31.1, R94.2
unnamed: D33.A, R97.1
unnamed: I2C32.3, R98.2
unnamed: I2C32.1, R99.2
unnamed: PWRLED32.1, R97.2
unnamed: D34.A, R100.1
unnamed: I2C33.3, R101.2
unnamed: I2C33.1, R102.2
unnamed: PWRLED33.1, R100.2
unnamed: D35.A, R103.1
unnamed: I2C34.3, R104.2
unnamed: I2C34.1, R105.2
unnamed: PWRLED34.1, R103.2
SCL: J1.4, J2.4, J4.4, R1.1, U1.2
SCL1: J3.4, J5.4, J6.4, R5.1, U2.2
SCL2: J7.4, J8.4, J9.4, R8.1, U3.2
SCL3: J10.4, J11.4, J12.4, R11.1, U4.2
SCL4: J13.4, J14.4, J15.4, R14.1, U5.2
SCL5: J16.4, J17.4, J18.4, R17.1, U6.2
SCL6: J19.4, J20.4, J21.4, R20.1, U7.2
SCL7: J22.4, J23.4, J24.4, R23.1, U8.2
SCL8: J25.4, J26.4, J27.4, R26.1, U9.2
SCL9: J28.4, J29.4, J30.4, R29.1, U10.2
SCL10: J31.4, J32.4, J33.4, R32.1, U11.2
SCL11: J34.4, J35.4, J36.4, R35.1, U12.2
SCL12: J37.4, J38.4, J39.4, R38.1, U13.2
SCL13: J40.4, J41.4, J42.4, R41.1, U14.2
SCL14: J43.4, J44.4, J45.4, R44.1, U15.2
SCL15: J46.4, J47.4, J48.4, R47.1, U16.2
SCL16: J49.4, J50.4, J51.4, R50.1, U17.2
SCL17: J52.4, J53.4, J54.4, R53.1, U18.2
SCL18: J55.4, J56.4, J57.4, R56.1, U19.2
SCL19: J58.4, J59.4, J60.4, R59.1, U20.2
SCL20: J61.4, J62.4, J63.4, R62.1, U21.2
SCL21: J64.4, J65.4, J66.4, R65.1, U22.2
SCL22: J67.4, J68.4, J69.4, R68.1, U23.2
SCL23: J70.4, J71.4, J72.4, R71.1, U24.2
SCL24: J73.4, J74.4, J75.4, R74.1, U25.2
SCL25: J76.4, J77.4, J78.4, R77.1, U26.2
SCL26: J79.4, J80.4, J81.4, R80.1, U27.2
SCL27: J82.4, J83.4, J84.4, R83.1, U28.2
SCL28: J85.4, J86.4, J87.4, R86.1, U29.2
SCL29: J88.4, J89.4, J90.4, R89.1, U30.2
SCL30: J91.4, J92.4, J93.4, R92.1, U31.2
SCL31: J94.4, J95.4, J96.4, R95.1, U32.2
SCL32: J97.4, J98.4, J99.4, R98.1, U33.2
SCL33: J100.4, J101.4, J102.4, R101.1, U34.2
SCL34: J103.4, J104.4, J105.4, R104.1, U35.2
SDA: J1.3, J2.3, J4.3, R2.1, U1.3
SDA1: J3.3, J5.3, J6.3, R6.1, U2.3
SDA2: J7.3, J8.3, J9.3, R9.1, U3.3
SDA3: J10.3, J11.3, J12.3, R12.1, U4.3
SDA4: J13.3, J14.3, J15.3, R15.1, U5.3
SDA5: J16.3, J17.3, J18.3, R18.1, U6.3
SDA6: J19.3, J20.3, J21.3, R21.1, U7.3
SDA7: J22.3, J23.3, J24.3, R24.1, U8.3
SDA8: J25.3, J26.3, J27.3, R27.1, U9.3
SDA9: J28.3, J29.3, J30.3, R30.1, U10.3
SDA10: J31.3, J32.3, J33.3, R33.1, U11.3
SDA11: J34.3, J35.3, J36.3, R36.1, U12.3
SDA12: J37.3, J38.3, J39.3, R39.1, U13.3
SDA13: J40.3, J41.3, J42.3, R42.1, U14.3
SDA14: J43.3, J44.3, J45.3, R45.1, U15.3
SDA15: J46.3, J47.3, J48.3, R48.1, U16.3
SDA16: J49.3, J50.3, J51.3, R51.1, U17.3
SDA17: J52.3, J53.3, J54.3, R54.1, U18.3
SDA18: J55.3, J56.3, J57.3, R57.1, U19.3
SDA19: J58.3, J59.3, J60.3, R60.1, U20.3
SDA20: J61.3, J62.3, J63.3, R63.1, U21.3
SDA21: J64.3, J65.3, J66.3, R66.1, U22.3
SDA22: J67.3, J68.3, J69.3, R69.1, U23.3
SDA23: J70.3, J71.3, J72.3, R72.1, U24.3
SDA24: J73.3, J74.3, J75.3, R75.1, U25.3
SDA25: J76.3, J77.3, J78.3, R78.1, U26.3
SDA26: J79.3, J80.3, J81.3, R81.1, U27.3
SDA27: J82.3, J83.3, J84.3, R84.1, U28.3
SDA28: J85.3, J86.3, J87.3, R87.1, U29.3
SDA29: J88.3, J89.3, J90.3, R90.1, U30.3
SDA30: J91.3, J92.3, J93.3, R93.1, U31.3
SDA31: J94.3, J95.3, J96.3, R96.1, U32.3
SDA32: J97.3, J98.3, J99.3, R99.1, U33.3
SDA33: J100.3, J101.3, J102.3, R102.1, U34.3
SDA34: J103.3, J104.3, J105.3, R105.1, U35.3

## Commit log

2020-03-30 pre review commit
    [SHTC3 Breakout.brd, SHTC3 Breakout.sch]
2020-03-31 post review/checklist changes, ready for QC double check
    [SHTC3 Breakout.brd, SHTC3 Breakout.sch]
2020-03-31 adding in production files
    [SHTC3 Breakout-Panel.GBL, SHTC3 Breakout-Panel.GBO, SHTC3 Breakout-Panel.GBP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]
2020-05-07 Deleting Test Sketch
    Test sketch is not needed as we have the Arduino Library. Removing.

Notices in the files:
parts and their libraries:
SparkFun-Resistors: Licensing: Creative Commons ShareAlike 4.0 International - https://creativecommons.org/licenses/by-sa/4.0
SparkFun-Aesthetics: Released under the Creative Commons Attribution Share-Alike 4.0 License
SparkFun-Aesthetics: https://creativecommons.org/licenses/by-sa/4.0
